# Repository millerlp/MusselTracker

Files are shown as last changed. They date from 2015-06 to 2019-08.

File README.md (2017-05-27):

This repository contains hardware designs and software to create a low-cost datalogger that can be used to track mussel (bivalve molluscs, not muscles) behavior  and temperature over long periods of time. The basic design includes a thermocouple temperature sensor, a hall effect magnetic sensor to sense valve gape, and a 3-D acclerometer/magnetometer to record mussel shell orientation.

Arduino-style code to run the datalogger is available the MusselTracker2 directory. The code requires the use of the MusselTrackerlib library available separately at https://github.com/millerlp/MusselTrackerlib 

Various testing code for individual sensors and the overall circuit board are available in the test_sketches directory. 

Circuit board designs are available in the Eagle_files directory.

Orginally a fork of https://github.com/andrewpetersen/MusselTracker/, now with a wholesale rewrite of the software and hardware. 

******************
    Copyright Luke Miller 2015

    This program is free software: you can redistribute it and/or modify
    it under the terms of the GNU General Public License as published by
    the Free Software Foundation, either version 3 of the License, or
    (at your option) any later version.

    This program is distributed in the hope that it will be useful,
    but WITHOUT ANY WARRANTY; without even the implied warranty of
    MERCHANTABILITY or FITNESS FOR A PARTICULAR PURPOSE.  See the
    GNU General Public License for more details.

    You should have received a copy of the GNU General Public License
    along with this program.  If not, see <http://www.gnu.org/licenses/>.

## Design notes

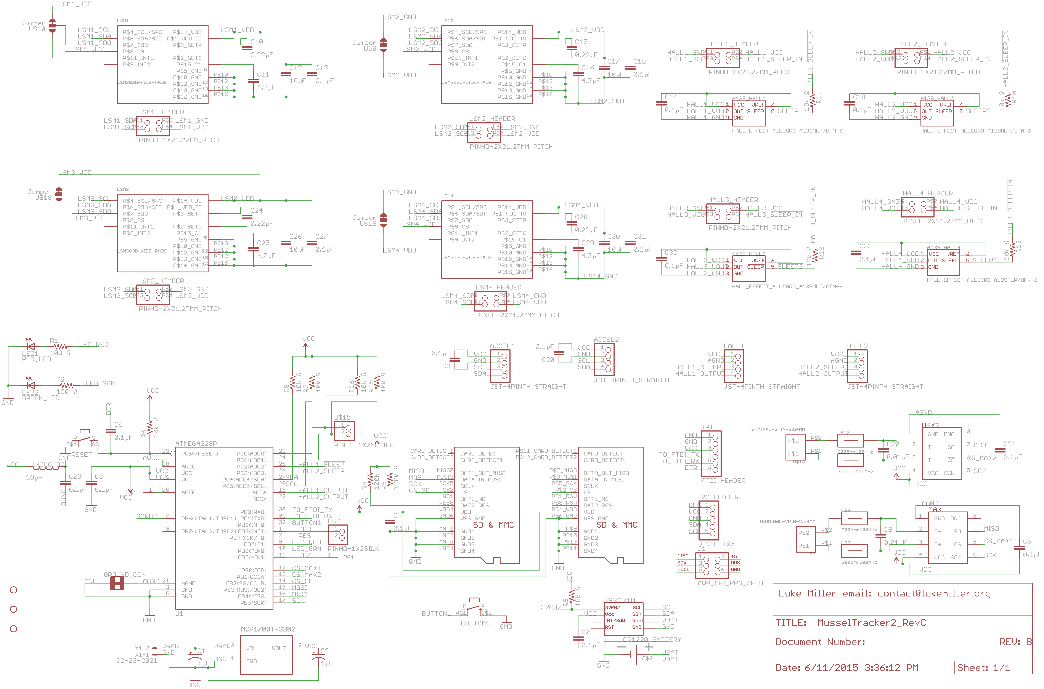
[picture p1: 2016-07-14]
Eagle_files/RevC_schematic.png

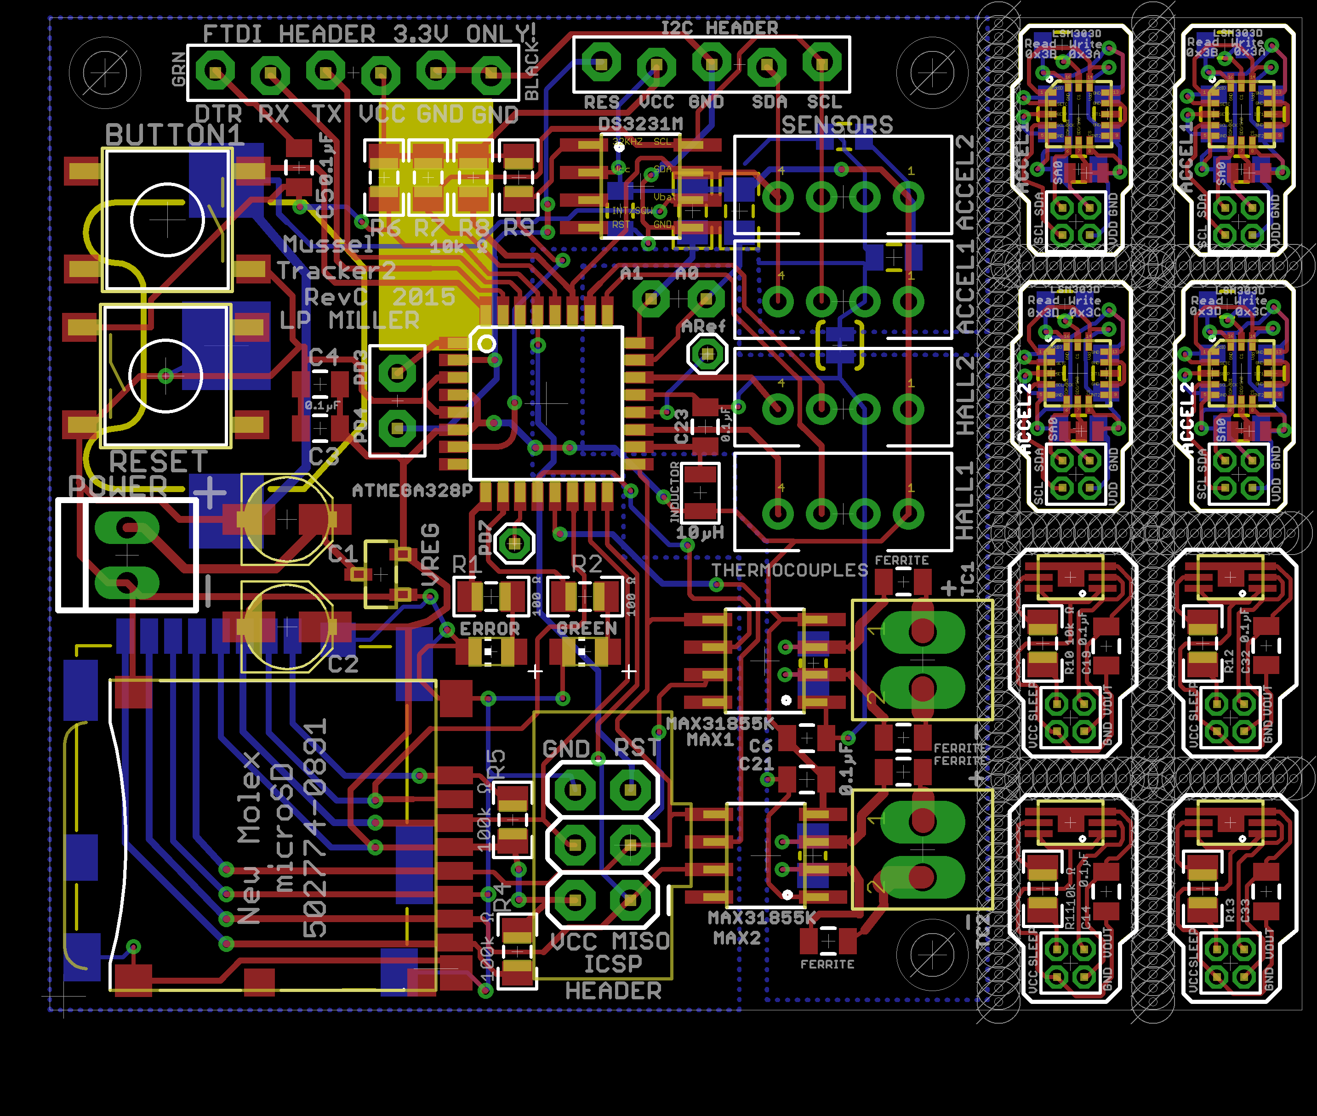
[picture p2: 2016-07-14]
Eagle_files/RevC_top_bottom.png

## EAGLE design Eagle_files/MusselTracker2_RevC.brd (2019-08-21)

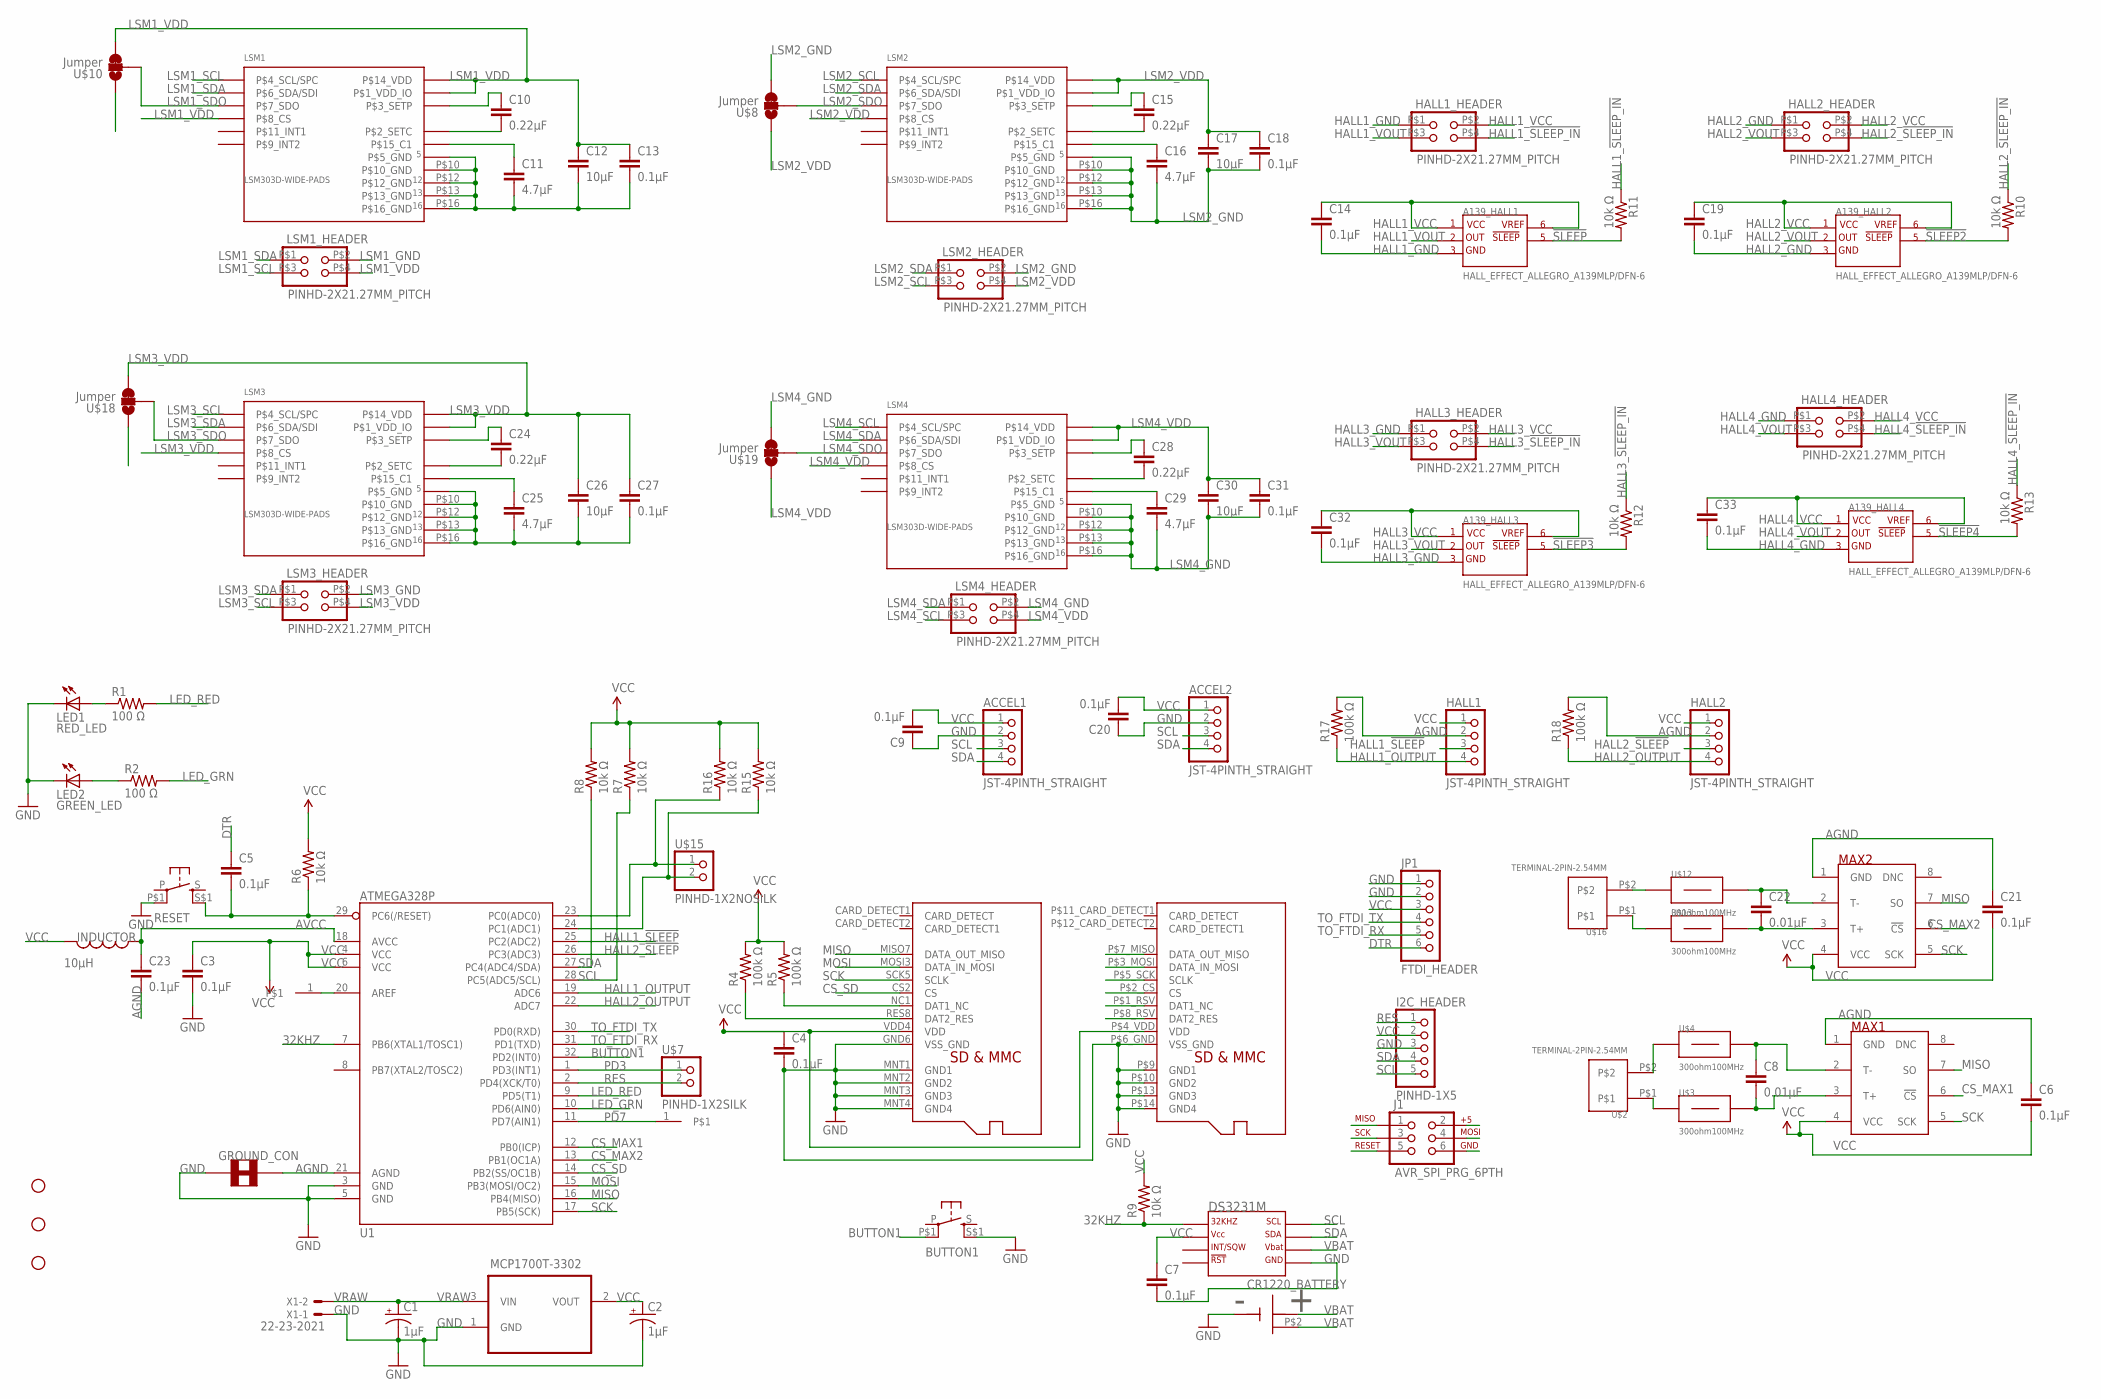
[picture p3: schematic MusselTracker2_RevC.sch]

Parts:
A139_HALL1, A139_HALL2, A139_HALL3, A139_HALL4: HALL_EFFECT_ALLEGRO_A139MLP/DFN-6; A139*_HALL_EFFECT
ACCEL1, ACCEL2: JST-4PINTH_STRAIGHT; JST-PH-4-THM
BUTTON1: PUSHBUTTON_DPST_SMD
C1, C2: 1µF; PANASONIC_B
C3, C4, C5, C6, C7, C9, C13, C14, C18, C19, C20, C21, C23, C27, C31, C32, C33: 0.1µF; 0805
C8, C22: 0.01µF; 0805_CAP_50V_KEMET
C10, C15, C24, C28: 0.22µF; 0805
C11, C16, C25, C29: 4.7µF; 0805
C12, C17, C26, C30: 10µF; 0805
CR1220_BATTERY: CR1220_BATTERY_HOLDERSMD; CR1220_BATTERY_HOLDER_SMD
DS3231M: DS3231MSOIC-8; DS3231M_SOIC8
GROUND_CON: SOLDER_JUMPER_TRACESTANDARD; SJ_2S-TRACE
HALL1, HALL2: JST-4PINTH_STRAIGHT; JST-PH-4-THM
HALL1_HEADER, HALL2_HEADER, HALL3_HEADER, HALL4_HEADER: PINHD-2X21.27MM_PITCH; 2X2_1.27MM
I2C_HEADER: PINHD-1X5; 1X05_BIGLOCK
INDUCTOR: 10µH; I_0805
J1: AVR_SPI_PRG_6PTH; 2X3
JP1: FTDI_HEADER; 1X06-BIGLOCK
LED1: RED_LED; CHIPLED_0805
LED2: GREEN_LED; CHIPLED_0805
LSM1, LSM2, LSM3, LSM4: LSM303D-WIDE-PADS; LSM303D
LSM1_HEADER, LSM2_HEADER, LSM3_HEADER, LSM4_HEADER: PINHD-2X21.27MM_PITCH; 2X2_1.27MM
MAX1, MAX2: MAX31855; SO08
MCP1700T-3302: MCP1700T-3302E/TT; SOT95P237X112-3N
R1, R2: 100 Ω; R0805
R4, R5, R17, R18: 100k Ω; R0805
R6, R7, R8, R9, R10, R11, R12, R13, R15, R16: 10k Ω; R0805
RESET: PUSHBUTTON_DPST_SMD
STANDOFF1, STANDOFF2, STANDOFF3: STAND-OFF
U1: ATMEGA328P; TQFP32-08
U$1: MICROSD_MOLEX_REVERSECURRENT; MICROSD_SOCKET_MOLEX_REVERSEMOUNT
U$2, U$16: TERMINAL-2PIN-2.54MM
U$3, U$4, U$12, U$13: 300ohm100MHz; 0805
U$6, U$17: PINHD-1X1SMALL; 1X01_SMALL
U$7: PINHD-1X2SILK; 1X02
U$8, U$10, U$18, U$19: Jumper; PAD-JUMPER-3-2OF3_NC_BY_TRACE_SMALL
U$14: MICROSD_MOLEX_REVERSEOBSOLETE; MICROSD_SOCKET_MOLEX_REVERSEMOUNT_OBSOLETE
U$15: PINHD-1X2NOSILK; 1X02_NOSILK
X1: 22-23-2021

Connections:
32KHZ: DS3231M.1 (P$1_32KHZ), R9.1, U1.7 (PB6(XTAL1/TOSC1))
!SLEEP: A139_HALL1.P$5, R11.2
!SLEEP2: A139_HALL2.P$5, R10.2
!SLEEP3: A139_HALL3.P$5, R12.2
!SLEEP4: A139_HALL4.P$5, R13.2
AGND: C6.1, C21.1, C23.2, GROUND_CON.2, HALL1.2, HALL2.2, MAX1.1 (GND), MAX2.1 (GND), R17.2, R18.2, U1.21 (AGND)
AVCC: C23.1, INDUCTOR.P$1 (1), U1.18 (AVCC)
BUTTON1: BUTTON1.P$1 (P1), U1.32 (PD2(INT0))
CS_MAX1: MAX1.6 (!CS), U1.12 (PB0(ICP))
CS_MAX2: MAX2.6 (!CS), U1.13 (PB1(OC1A))
CS_SD: U1.14 (PB2(SS/OC1B)), U$1.CS2 (CS), U$14.P$2_CS (CS)
DTR: C5.1, JP1.6
GND: ACCEL1.2, ACCEL2.2, BUTTON1.S$1 (S1), C1.-, C2.-, C3.2, C4.2, C7.2, C9.1, C20.1, CR1220_BATTERY.GND, DS3231M.5 (P$5_GND), GROUND_CON.1, I2C_HEADER.3, J1.6, JP1.1, JP1.2, LED1.C, LED2.C, MCP1700T-3302.1 (GND), RESET.P$1 (P1), U1.3 (GND), U1.5 (GND), U$1.GND6 (VSS_GND), U$1.MNT1 (GND1), U$1.MNT2 (GND2), U$1.MNT3 (GND3), U$1.MNT4 (GND4), U$14.P$6_GND (VSS_GND), U$14.P$9 (GND1), U$14.P$10 (GND2), U$14.P$13 (GND3), U$14.P$14 (GND4), X1.1
HALL1_!SLEEP: HALL1.3, U1.25 (PC2(ADC2))
HALL1_!SLEEP_IN: HALL1_HEADER.P$4 (4), R11.1
HALL1_GND: A139_HALL1.P$3_4, C14.2, HALL1_HEADER.P$1 (1)
HALL1_OUTPUT: HALL1.4, R17.1, U1.19 (ADC6)
HALL1_VCC: A139_HALL1.P$1, A139_HALL1.P$6, C14.1, HALL1_HEADER.P$2 (2)
HALL1_VOUT: A139_HALL1.P$2, HALL1_HEADER.P$3 (3)
HALL2_!SLEEP: HALL2.3, U1.26 (PC3(ADC3))
HALL2_!SLEEP_IN: HALL2_HEADER.P$4 (4), R10.1
HALL2_GND: A139_HALL2.P$3_4, C19.2, HALL2_HEADER.P$1 (1)
HALL2_OUTPUT: HALL2.4, R18.1, U1.22 (ADC7)
HALL2_VCC: A139_HALL2.P$1, A139_HALL2.P$6, C19.1, HALL2_HEADER.P$2 (2)
HALL2_VOUT: A139_HALL2.P$2, HALL2_HEADER.P$3 (3)
HALL3_!SLEEP_IN: HALL3_HEADER.P$4 (4), R12.1
HALL3_GND: A139_HALL3.P$3_4, C32.2, HALL3_HEADER.P$1 (1)
HALL3_VCC: A139_HALL3.P$1, A139_HALL3.P$6, C32.1, HALL3_HEADER.P$2 (2)
HALL3_VOUT: A139_HALL3.P$2, HALL3_HEADER.P$3 (3)
HALL4_!SLEEP_IN: HALL4_HEADER.P$4 (4), R13.1
HALL4_GND: A139_HALL4.P$3_4, C33.2, HALL4_HEADER.P$1 (1)
HALL4_VCC: A139_HALL4.P$1, A139_HALL4.P$6, C33.1, HALL4_HEADER.P$2 (2)
HALL4_VOUT: A139_HALL4.P$2, HALL4_HEADER.P$3 (3)
LED_GRN: R2.2, U1.10 (PD6(AIN0))
LED_RED: R1.2, U1.9 (PD5(T1))
LSM1_GND: C11.2, C12.2, C13.2, LSM1.P$5 (P$5_GND), LSM1.P$10 (P$10_GND), LSM1.P$12 (P$12_GND), LSM1.P$13 (P$13_GND), LSM1.P$16 (P$16_GND), LSM1_HEADER.P$2 (2), U$10.1
LSM1_SCL: LSM1.P$4 (P$4_SCL/SPC), LSM1_HEADER.P$3 (3)
LSM1_SDA: LSM1.P$6 (P$6_SDA/SDI), LSM1_HEADER.P$1 (1)
LSM1_SDO: LSM1.P$7 (P$7_SDO), U$10.2
LSM1_VDD: C12.1, C13.1, LSM1.P$1 (P$1_VDD_IO), LSM1.P$8 (P$8_CS), LSM1.P$14 (P$14_VDD), LSM1_HEADER.P$4 (4), U$10.3
LSM2_GND: C16.2, C17.2, C18.2, LSM2.P$5 (P$5_GND), LSM2.P$10 (P$10_GND), LSM2.P$12 (P$12_GND), LSM2.P$13 (P$13_GND), LSM2.P$16 (P$16_GND), LSM2_HEADER.P$2 (2), U$8.3
LSM2_SCL: LSM2.P$4 (P$4_SCL/SPC), LSM2_HEADER.P$3 (3)
LSM2_SDA: LSM2.P$6 (P$6_SDA/SDI), LSM2_HEADER.P$1 (1)
LSM2_SDO: LSM2.P$7 (P$7_SDO), U$8.2
LSM2_VDD: C17.1, C18.1, LSM2.P$1 (P$1_VDD_IO), LSM2.P$8 (P$8_CS), LSM2.P$14 (P$14_VDD), LSM2_HEADER.P$4 (4), U$8.1
LSM3_GND: C25.2, C26.2, C27.2, LSM3.P$5 (P$5_GND), LSM3.P$10 (P$10_GND), LSM3.P$12 (P$12_GND), LSM3.P$13 (P$13_GND), LSM3.P$16 (P$16_GND), LSM3_HEADER.P$2 (2), U$18.1
LSM3_SCL: LSM3.P$4 (P$4_SCL/SPC), LSM3_HEADER.P$3 (3)
LSM3_SDA: LSM3.P$6 (P$6_SDA/SDI), LSM3_HEADER.P$1 (1)
LSM3_SDO: LSM3.P$7 (P$7_SDO), U$18.2
LSM3_VDD: C26.1, C27.1, LSM3.P$1 (P$1_VDD_IO), LSM3.P$8 (P$8_CS), LSM3.P$14 (P$14_VDD), LSM3_HEADER.P$4 (4), U$18.3
LSM4_GND: C29.2, C30.2, C31.2, LSM4.P$5 (P$5_GND), LSM4.P$10 (P$10_GND), LSM4.P$12 (P$12_GND), LSM4.P$13 (P$13_GND), LSM4.P$16 (P$16_GND), LSM4_HEADER.P$2 (2), U$19.3
LSM4_SCL: LSM4.P$4 (P$4_SCL/SPC), LSM4_HEADER.P$3 (3)
LSM4_SDA: LSM4.P$6 (P$6_SDA/SDI), LSM4_HEADER.P$1 (1)
LSM4_SDO: LSM4.P$7 (P$7_SDO), U$19.2
LSM4_VDD: C30.1, C31.1, LSM4.P$1 (P$1_VDD_IO), LSM4.P$8 (P$8_CS), LSM4.P$14 (P$14_VDD), LSM4_HEADER.P$4 (4), U$19.1
MISO: J1.1, MAX1.7 (SO), MAX2.7 (SO), U1.16 (PB4(MISO)), U$1.MISO7 (DATA_OUT_MISO), U$14.P$7_MISO (DATA_OUT_MISO)
MOSI: J1.4, U1.15 (PB3(MOSI/OC2)), U$1.MOSI3 (DATA_IN_MOSI), U$14.P$3_MOSI (DATA_IN_MOSI)
unnamed: U$2.P$2, U$4.1
unnamed: LED1.A, R1.1
unnamed: U$2.P$1, U$3.1
unnamed: C11.1, LSM1.P$15 (P$15_C1)
unnamed: C10.2, LSM1.P$2 (P$2_SETC)
unnamed: R16.1, U1.23 (PC0(ADC0)), U$15.1
unnamed: U1.20 (AREF), U$17.1
unnamed: R15.1, U1.24 (PC1(ADC1)), U$15.2
unnamed: LED2.A, R2.1
unnamed: U$12.1, U$16.P$2
unnamed: U$13.1, U$16.P$1
unnamed: C24.2, LSM3.P$2 (P$2_SETC)
unnamed: C24.1, LSM3.P$3 (P$3_SETP)
unnamed: C10.1, LSM1.P$3 (P$3_SETP)
unnamed: C15.2, LSM2.P$2 (P$2_SETC)
unnamed: C15.1, LSM2.P$3 (P$3_SETP)
unnamed: C16.1, LSM2.P$15 (P$15_C1)
unnamed: C25.1, LSM3.P$15 (P$15_C1)
unnamed: C28.1, LSM4.P$3 (P$3_SETP)
unnamed: C28.2, LSM4.P$2 (P$2_SETC)
unnamed: C29.1, LSM4.P$15 (P$15_C1)
NC1: R5.1, U$1.NC1 (DAT1_NC), U$14.P$1_RSV (DAT1_NC)
PD3: U1.1 (PD3(INT1)), U$7.1
PD7: U1.11 (PD7(AIN1)), U$6.1
RES: I2C_HEADER.1, U1.2 (PD4(XCK/T0)), U$7.2
RES8: R4.1, U$1.RES8 (DAT2_RES), U$14.P$8_RSV (DAT2_RES)
RESET: C5.2, J1.5, R6.1, RESET.S$1 (S1), U1.29 (PC6(/RESET))
SCK: J1.3, MAX1.5 (SCK), MAX2.5 (SCK), U1.17 (PB5(SCK)), U$1.SCK5 (SCLK), U$14.P$5_SCK (SCLK)
SCL: ACCEL1.3, ACCEL2.3, DS3231M.8 (P$8_SCL), I2C_HEADER.5, R7.1, U1.28 (PC5(ADC5/SCL))
SDA: ACCEL1.4, ACCEL2.4, DS3231M.7 (P$7_SDA), I2C_HEADER.4, R8.1, U1.27 (PC4(ADC4/SDA))
T+_MAX1: C8.2, MAX1.3 (T+), U$3.2
T+_MAX2: C22.2, MAX2.3 (T+), U$13.2
T-_MAX1: C8.1, MAX1.2 (T-), U$4.2
T-_MAX2: C22.1, MAX2.2 (T-), U$12.2
TO_FTDI_RX: JP1.5, U1.31 (PD1(TXD))
TO_FTDI_TX: JP1.4, U1.30 (PD0(RXD))
VBAT: CR1220_BATTERY.P$1 (VBAT), CR1220_BATTERY.P$2, DS3231M.6 (P$6_VBAT)
VCC: ACCEL1.1, ACCEL2.1, C2.+, C3.1, C4.1, C6.2, C7.1, C9.2, C20.2, C21.2, DS3231M.2 (P$2_VCC), HALL1.1, HALL2.1, I2C_HEADER.2, INDUCTOR.P$2 (2), J1.2, JP1.3, MAX1.4 (VCC), MAX2.4 (VCC), MCP1700T-3302.2 (VOUT), R4.2, R5.2, R6.2, R7.2, R8.2, R9.2, R15.2, R16.2, U1.4 (VCC), U1.6 (VCC), U$1.VDD4 (VDD), U$14.P$4_VDD (VDD)
VRAW: C1.+, MCP1700T-3302.3 (VIN), X1.2

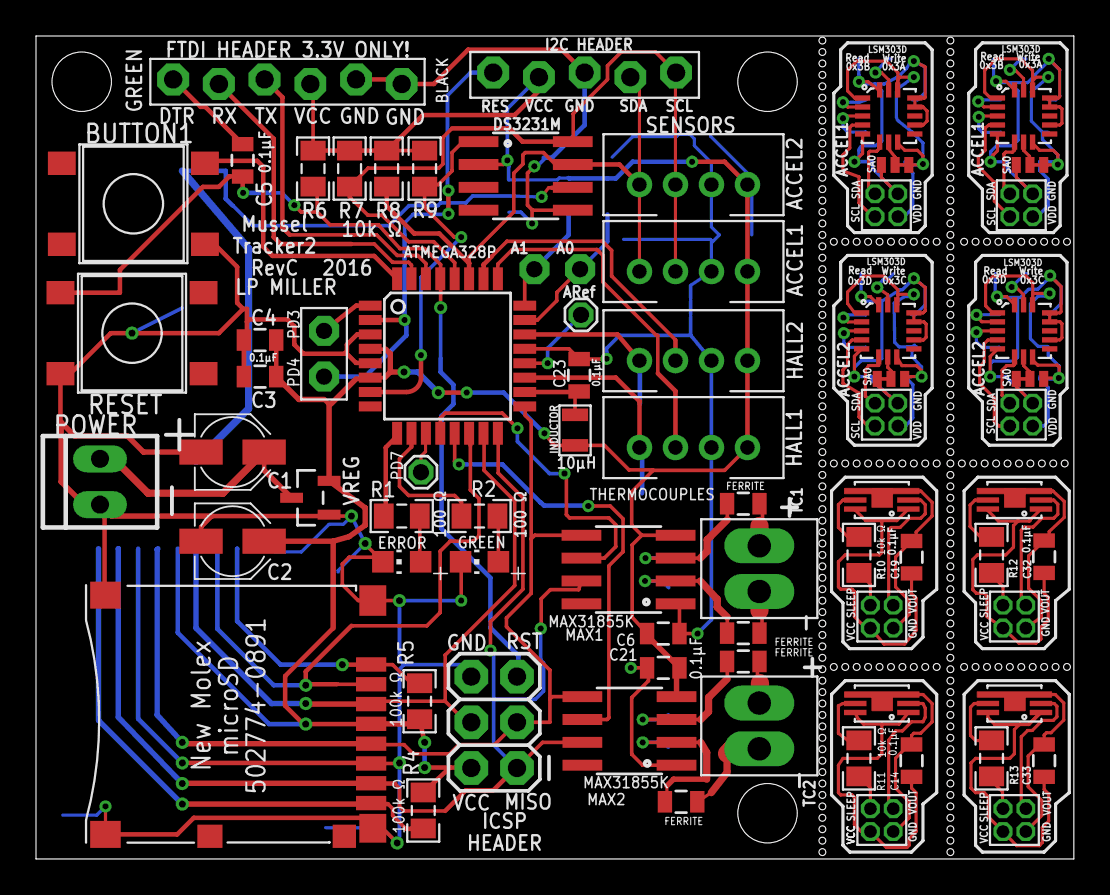
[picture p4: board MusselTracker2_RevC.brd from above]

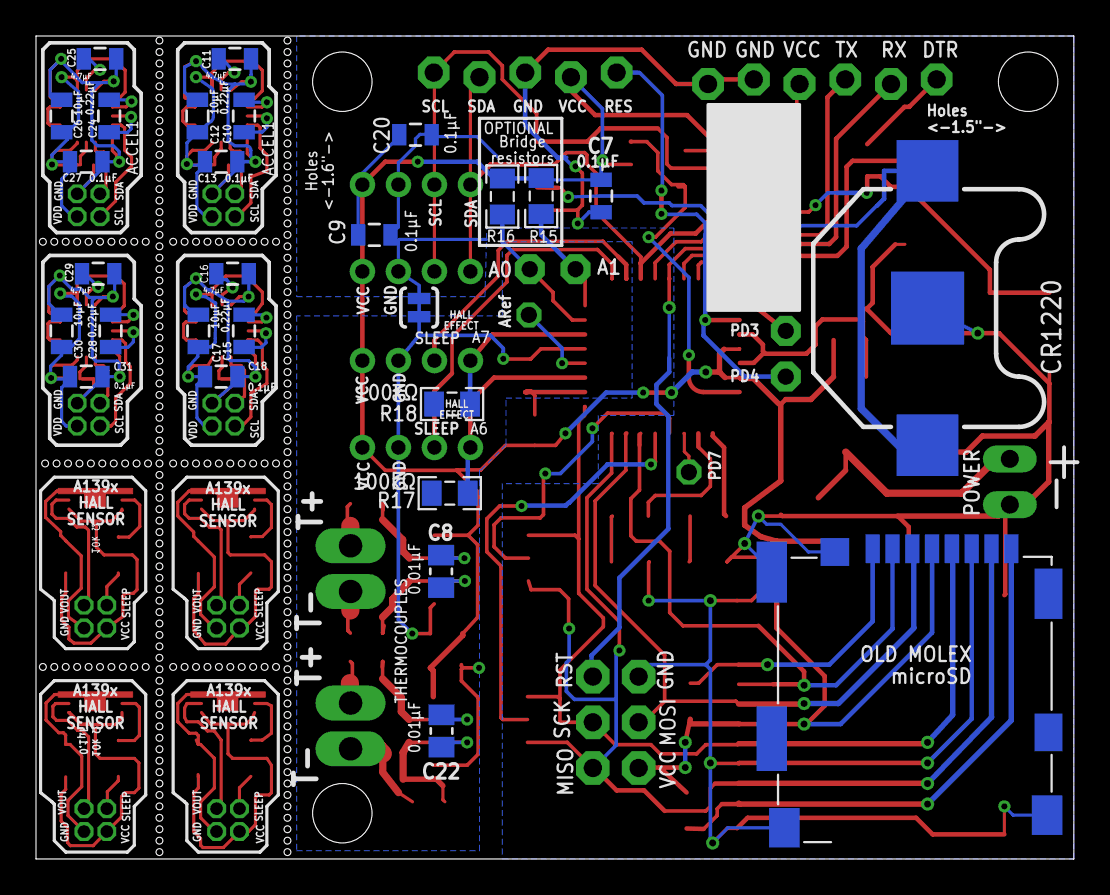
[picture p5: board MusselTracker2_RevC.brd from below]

Board: 2 copper layers, 57.7 x 45.7 mm, 104 parts (28 on the bottom side), 96 nets.

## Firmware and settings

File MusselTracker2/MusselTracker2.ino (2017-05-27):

/* MusselTrackerv2.ino
	Copyright Luke Miller 2015

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
  Code to run a MusselTracker v2 board with attached pairs of
  MAX31855 thermocouple sensors, Allegro A1393 hall effect
  sensors, and LSM303D accelerometer/magnetometers. By default
  this program will start running and saving data to the SD 
  card automatically. 
  
	Entering calibration mode:
		1. Hold button 1 down for at least 3 seconds, but less than 5 seconds
		2. Both red and green leds will flash 5 times when you enable 
			calibration mode. 
		3. You then have ~3 seconds to press button1 again
			to choose whether to calibrate mussel 1 or 2. 
		4. Pressing button1 repeatedly will cycle through 1 flash 
			(mussel 1), 2 flashes (mussel 2) or a red flash (no mussel chosen). 
		5. Once you've chosen the mussel, wait a few seconds for both red and
			green LEDs to flash once. 
		6. The green led will then slowly cycle on and off (1Hz) while it waits 
			for you to get the mussel situated.
		7. With the mussel situated facing north, press button1 briefly to 
			enter the calibration data collection mode. 
		8. When you have finished taking calibration data, press button1 again
			to exit calibration mode and return to normal data collection mode. 
			The red and green LEDs will flash 5 times to denote the end of 
			calibration mode. 
		
	Closing a data file safely:
		1. Hold button 1 down for at least 7 seconds, then release it.
		2. The green LED should flash rapidly 15 times. The previous data
			file will be closed safely, and a new file will be started in
			normal data collection mode. 
  
	Board error codes:
		Red flashes quickly (10Hz): Real Time Clock not set
		Red + Green alternate rapidly: SD card not found
                Red permanently on: SD card not found after data collection started
		Red flash every ~8 seconds: In brownout mode, data collection has stopped

	
	Sensor error codes:
		At the top of every minute, the green LED will flash quickly 5
		times. This lets the user know that error codes will follow 
		during the following 6 seconds, one signal per second. 
		As each second ticks by (1-6), the red error LED will light once 
		if a sensor error code is set for that sensor. The ordering of the 6 potential flashes is:
			1. Accelerometer/magnetometer 1
			2. Accelerometer/magnetometer 2
			3. Thermocouple 1
			4. Thermocouple 2
			5. Hall effect sensor 1
			6. Hall effect sensor 2
		You will need to count off the seconds in your head after you see 
		the 5 quick green flashes to determine which error is being 
		signaled. If there are no errors, the red error LED will not light 
		during this time. 

*/

#include "SdFat.h" // https://github.com/greiman/SdFat
#include <Wire.h>	// built in library, for I2C communications
#include <SPI.h>	// built in library, for SPI communications
#include <EEPROM.h> // built in library, for reading the serial number stored in EEPROM
#include "RTClib.h" // https://github.com/millerlp/RTClib
#include "Adafruit_MAX31855.h" // https://github.com/adafruit/Adafruit-MAX31855-library
#include "LSM303.h" // https://github.com/pololu/lsm303-arduino
#include "MusselTrackerlib.h"	// https://github.com/millerlp/MusselTrackerlib

//******************************
// Data collection rate, enter a value here of 4, 2, or 1 (samples per second)
#define SAMPLES_PER_SECOND 4 // number of samples taken per second (4, 2, or 1)
//******************************

#define ERRLED 5		// Red error LED pin
#define GREENLED 6		// Green LED pin
#define BUTTON1 2 		// BUTTON1 on INT0, pin PD2

// Comment out the following line to remove parts of the
// test code from functioning. 
#define ECHO_TO_SERIAL // For testing serial output over FTDI adapter

// Interval to flash green LED during normal data collection
// For every 10 seconds, enter 10, for every 30 seconds, enter 30
#define PULSE_INTERVAL 10

// ***** TYPE DEFINITIONS *****
typedef enum STATE
{
  STATE_DATA, // collecting data normally
  STATE_ENTER_CALIB, // user wants to calibrate
  STATE_CALIB1, // user chooses to calibrate accel 1
  STATE_CALIB2, // user chooses to calibrate accel 2
  STATE_CALIB_WAIT, // waiting for user to signal mussel is positioned
  STATE_CALIB_ACTIVE, // taking calibration data, button press ends this
  STATE_CLOSE_FILE, // close data file, start new file
} mainState_t;

typedef enum DEBOUNCE_STATE
{
  DEBOUNCE_STATE_IDLE,
  DEBOUNCE_STATE_CHECK,
  DEBOUNCE_STATE_TIME
} debounceState_t;

// main state machine variable, this takes on the various
// values defined for the STATE typedef above. 
mainState_t mainState;

// debounce state machine variable, this takes on the various
// values defined for the DEBOUNCE_STATE typedef above.
volatile debounceState_t debounceState;

//*************
// Create real time clock object
RTC_DS3231 rtc;


//*************
// Create sd card objects
SdFat sd;
SdFile logfile;  // for sd card, this is the file object to be written to
SdFile calibfile; // for sd card, this is the calibration file to write
const byte chipSelect = 10; // define the Chip Select pin for SD card

//************
// Define MAX31855 objects, need 2 of them for the two separate chips
#define CS_MAX1 8 // Chip Select for MAX31855 #1
#define CS_MAX2 9 // Chip Select for MAX31855 #2
Adafruit_MAX31855 thermocouple1(CS_MAX1);
Adafruit_MAX31855 thermocouple2(CS_MAX2);
double temp1 = 0; // hold output from MAX31855 #1
double temp2 = 0; // hold output from MAX31855 #2

//*************
// Define LSM303 accelerometer/magnetometer objects
LSM303 accelcompass1;
LSM303 accelcompass2;

//*************
// Define a HallSensor object (from MusselTrackerlib.h library)
// to access the hall effect sensor functions available in that
// library. 
HallSensor hallsensor;
// Variables to hold hall effect readings
int hallVal1 = 0;
int hallVal2 = 0;
// The HallSensor functions will require an argument to 
// specify which sensor your want, HALL1 or HALL2, so you 
// must always specify that in the hall effect sensor
// function calls. 

// Declare data arrays
uint32_t unixtimeArray[SAMPLES_PER_SECOND]; // store unixtime values temporarily
byte fracSecArray[SAMPLES_PER_SECOND]; // store fracSec values temporarily
int accelcompass1Array[SAMPLES_PER_SECOND][6]; // store accel/compass1 values
int accelcompass2Array[SAMPLES_PER_SECOND][6]; // store accel/compass2 values

int accMagCheck[4]; // store a value from each accel/mag sensor to compare to new values
unsigned int accMagCheckCount[4]; // count up number of matches
unsigned int maxRepeats = 120; // maximum number of accel/mag repeated values allowed before throwing error flag

// Declare initial name for output files written to SD card
char filename[] = "YYYYMMDD_HHMM_00_SN00.csv";
// Define initial name of calibration file for accelerometers
char filenameCalib[] = "CAL0_YYYYMMDD_HHMM_00_SN00.csv";
// Placeholder serialNumber
char serialNumber[] = "SN00";
// Define a flag to show whether the serialNumber value is real or just zeros
bool serialValid = false;
byte mcusr = 0; 	// variable to hold MCU status register codes
byte loopCount = 0; // counter to keep track of data sampling loops
byte fracSec = 0; // counter to keep track of fractional seconds
DateTime newtime; // used to track time in main loop
DateTime oldtime; // used to track time in main loop
byte oldday; 		// used to keep track of midnight transition
DateTime buttonTime; // hold the time since the button was pressed
DateTime chooseTime; // hold the time stamp when a waiting period starts
DateTime calibEnterTime; // hold the time stamp when calibration mode is entered
volatile unsigned long buttonTime1; // hold the initial button press millis() value
byte debounceTime = 20; // milliseconds to wait for debounce
volatile bool buttonFlag = false; // Flag to mark when button was pressed
byte mediumPressTime = 2; // seconds to hold button1 to register a medium press
byte longPressTime = 5; // seconds to hold button1 to register a long press
byte pressCount = 0; // counter for number of button presses
unsigned long prevMillis;	// counter for faster operations
unsigned long newMillis;	// counter for faster operations
// Flags to mark when sensors go bad
bool tc1fail = false;
bool tc2fail = false;
bool hall1fail = false;
bool hall2fail = false;
bool accel1fail = false;
bool accel2fail = false;
// Define two temperature limits for the thermocouples, values outside
// this range will trigger the error notification
float TClowerlimit = 0.0;
float TCupperlimit = 60.0;
int aaFilterBW;		// store accelerometer anti-alias filter bandwidth
byte accFullScale; 	// store accelerometer full scale range +/- g
float accSens; 	// store accelerometer sensitivity (mg/LSB)
int accDataRate;	// store accelerometer sample rate (not the same as datalogger sample rate)
byte magFullScale;	// store magnetometer full scale range (gauss)
float magSens;		// store magnetometer sensitivity (mgauss/LSB)
float magDataRate;	// store magnetometer sample rate (not the same as datalogger sample rate)
//---------------- setup loop ------------------------------------------------
void setup() {
	// Set button1 as an input
	pinMode(BUTTON1, INPUT_PULLUP);
	// Register an interrupt on INT0, attached to button1
	// which will call buttonFunc when the button is pressed.
	attachInterrupt(0, buttonFunc, LOW);
	// Set up the LEDs as output
	pinMode(ERRLED,OUTPUT);
	digitalWrite(ERRLED, LOW);
	pinMode(GREENLED,OUTPUT);
	digitalWrite(GREENLED, LOW);
	// Set the SPI bus chip select pins as outputs
	// for the two MAX31855 thermocouple chips
	pinMode(CS_MAX1, OUTPUT);
	digitalWrite(CS_MAX1, HIGH);
	pinMode(CS_MAX2, OUTPUT);
	digitalWrite(CS_MAX2, HIGH);

	pinMode(4, OUTPUT);
	pinMode(3, OUTPUT);
	
	// Flash green LED to show that we just booted up
	for (byte i = 0; i < 3; i++){
		digitalWrite(GREENLED, HIGH);
		delay(100);
		digitalWrite(GREENLED, LOW);
		delay(100);
	}	
	
	// Brownout detection process.
	mcusr = MCUSR; // Grab the contents of the MCUSR
	MCUSR = 0; // Reset MCUSR to 0 so it is ready for the next go-around.
	// Call the checkMCUSR function to check reason for this restart.
	// If only a brownout is detected, this function will put the board
	// into a permanent sleep that can only be reset with the reset 
	// button or a complete power-down.
	checkMCUSR(mcusr, ERRLED);  // In the MusselTrackerlib library
								
	Serial.begin(57600);
#ifdef ECHO_TO_SERIAL  
	Serial.println(F("Hello"));
	Serial.print(F("MCUSR contents: "));
	printBits(mcusr);
	Serial.println();
	
#endif
	
	// Grab the serial number from the EEPROM memory
	// The character array serialNumber was defined in the preamble
	EEPROM.get(0, serialNumber);
	if (serialNumber[0] == 'S') {
		serialValid = true; // set flag
#ifdef ECHO_TO_SERIAL		
		Serial.print(F("Read serial number: "));
		Serial.println(serialNumber);
#endif		
	} else {
#ifdef ECHO_TO_SERIAL	
		Serial.print(F("No valid serial number: "));
		Serial.println(serialNumber);
		serialValid = false;
#endif		
	}

	// Initialize the Allegro A1393 hall effect sensors
	// There is only one hallsensor object, but you feed it
	// HALL1 or HALL2 as an argument to specify which channel
	// you want to activate and read. 
	hallsensor.begin(HALL1);
	hallsensor.begin(HALL2);

	// Initialize the real time clock DS3231M
	Wire.begin();	// Start the I2C library with default options
	rtc.begin();	// Start the rtc object with default options
	newtime = rtc.now(); // read a time from the real time clock
	printTimeSerial(rtc.now()); // print time to serial monitor
	Serial.println();
	if (newtime.year() < 2015 | newtime.year() > 2035) {
		// There is an error with the clock, halt everything
		while(1){
		// Flash the error led to notify the user
		// This permanently halts execution, no data will be collected
			digitalWrite(ERRLED, !digitalRead(ERRLED));
			delay(100);
		}	
	}

//***************************************
	// Initialize the accelerometer/compass
	// For the LSM303D that has its sa0 pin pulled high (ACCEL1),
	// use the arguments accelcompass1.init(LSM303::device_D, LSM303::sa0_high)
	// to tell the initialization function to look for the correct device
	// When a device type and sa0 pin state are defined, the init() function 
	// will always return true.
	accelcompass1.init(LSM303::device_D, LSM303::sa0_high);
	accelcompass1.enableDefault();
	// Use sa0_low argument for the other accelerometer that has its address 
	// pin set to ground. 
	accelcompass2.init(LSM303::device_D, LSM303::sa0_low);
	accelcompass2.enableDefault();
	// You must set a timeout to handle cases where the sensor dies
	// or otherwise can't be found on the I2C bus, which would hang
	// the whole program without a timeout.
	accelcompass1.setTimeout(20); 
	accelcompass2.setTimeout(20);
	
	// Now set both accelerometers to sample based on the settings
	// in the function accelNormalMode()
	accelNormalMode(accelcompass1);
	accelNormalMode(accelcompass2);
	delay(5);
	// Read back the settings so they can be written to file headers
	getaccelSettings(accelcompass1);
	getaccelSettings(accelcompass2);
//*************************************************************
// SD card setup and read (assumes Serial output is functional already)
	pinMode(chipSelect, OUTPUT);  // set chip select pin for SD card to output
	// Initialize the SD card object
	// Try SPI_FULL_SPEED, or SPI_HALF_SPEED if full speed produces
	// errors on a breadboard setup. 
	if (!sd.begin(chipSelect, SPI_FULL_SPEED)) {
	// If the above statement returns FALSE after trying to 
	// initialize the card, enter into this section and
	// hold in an infinite loop.
		while(1){ // infinite loop due to SD card initialization error
                        digitalWrite(ERRLED, HIGH);
                        delay(100);
                        digitalWrite(ERRLED, LOW);
                        digitalWrite(GREENLED, HIGH);
                        delay(100);
                        digitalWrite(GREENLED, LOW);
		}
	}
	newtime = rtc.now(); // grab the current time
	initFileName(newtime); // generate a file name
	
#ifdef ECHO_TO_SERIAL		
		Serial.print("Writing to ");
		Serial.println(filename);
#endif
	// Start 32.768kHz clock signal on TIMER2. 
	// Supply the current time value as the argument, returns 
	// an updated time
	newtime = startTIMER2(rtc.now());
	
	oldtime = newtime; // store the current time value
	oldday = oldtime.day(); // store the current day value
	
	mainState = STATE_DATA; // Start the main loop in data-taking state
}

void loop() {
	delay(2); // trying this to quell bogus sd writes
	// Always start the loop by checking the time
	newtime = rtc.now(); // Grab the current time
	
	
	//-------------------------------------------------------------
	// Begin loop by checking the debounceState to 
	// handle any button presses
 	switch (debounceState) {
		// debounceState should normally start off as 
		// DEBOUNCE_STATE_IDLE until button1 is pressed,
		// which causes the state to be set to 
		// DEBOUNCE_STATE_CHECK
		//************************************
		case DEBOUNCE_STATE_IDLE:
			// Do nothing in this case
		break;
		//************************************
		case DEBOUNCE_STATE_CHECK:
			// If the debounce state has been set to 
			// DEBOUNCE_STATE_CHECK by the buttonFunc interrupt,
			// check if the button is still pressed
			if (digitalRead(BUTTON1) == LOW) {
				if (millis() > buttonTime1 + debounceTime) {
					// If the button has been held long enough to 
					// be a legit button press, switch to 
					// DEBOUNCE_STATE_TIME to keep track of how long 
					// the button is held
					debounceState = DEBOUNCE_STATE_TIME;
					buttonTime = rtc.now();
				} else {
					// If button is still pressed, but the debounce 
					// time hasn't elapsed, remain in this state
					debounceState = DEBOUNCE_STATE_CHECK;
				}
			} else {
				// If button1 is high again when we hit this
				// case in DEBOUNCE_STATE_CHECK, it was a false trigger
				// Reset the debounceState
				debounceState = DEBOUNCE_STATE_IDLE;
				buttonFlag = false;
				// Restart the button1 interrupt
				attachInterrupt(0, buttonFunc, LOW);
			}
		break; // end of case DEBOUNCE_STATE_CHECK
		//*************************************
		case DEBOUNCE_STATE_TIME:
			if (digitalRead(BUTTON1) == HIGH) {
				// If the user released the button, now check how
				// long the button was depressed. This will determine
				// which state the user wants to enter.
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

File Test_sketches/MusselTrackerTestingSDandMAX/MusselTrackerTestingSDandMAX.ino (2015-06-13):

/* MusselTrackerTesting
  Code to test what portions of a newly assembled 
  Mussel Tracker v2 board are functional
  
  **Tested as working on 2015-06-11 on a 
  Mussel Tracker v2 RevB circuit board with the
  fix applied to supply VCC power to MAX31855 chip 2

*/

#include "SdFat.h" // https://github.com/greiman/SdFat
#include <Wire.h>
#include <SPI.h>
#include "RTClib.h" // https://github.com/millerlp/RTClib
#include <Adafruit_MAX31855.h> // https://github.com/adafruit/Adafruit-MAX31855-library


#define ERRLED 5
#define GREENLED 6

// Comment out any of the following 4 lines to remove parts of the
// test code from functioning. 
#define Serialtest // For testing serial output over FTDI adapter
#define RTCtest // For testing DS3231 function (requires Serial to be working)
#define SDtest	// For testing SD card slot function, requires Serial to be working
#define MAXtest // For testing MAX31855 thermocouple 

// Create real time clock object
RTC_DS3231 RTC;

// Create sd objects
SdFat sd;
SdFile logfile;  // for sd card, this is the file object to be written to
SdFile setfile; // for sd card, this is the settings file to read from
const byte chipSelect = 10; // define the Chip Select pin for SD card
// Serial streams
ArduinoOutStream cout(Serial);


#define CS_MAX1 8 // Chip Select for MAX31855 #1
#define CS_MAX2 9 // Chip Select for MAX31855 #2
// Define MAX31855 objects, need 2 of them for the two separate chips
Adafruit_MAX31855 thermocouple1(CS_MAX1);
Adafruit_MAX31855 thermocouple2(CS_MAX2);
double temp1 = 0; // hold output from MAX31855 #1
double temp2 = 0; // hold output from MAX31855 #2

void setup() {


  // put your setup code here, to run once:
#ifdef Serialtest  
  Serial.begin(57600);
  Serial.println("Hello");
#endif
  
  pinMode(ERRLED,OUTPUT);
  digitalWrite(ERRLED, LOW);
  pinMode(GREENLED,OUTPUT);
  digitalWrite(GREENLED, LOW);
  
	// Set the chip select pins as outputs
	pinMode(CS_MAX1, OUTPUT);
	digitalWrite(CS_MAX1, HIGH);
	pinMode(CS_MAX2, OUTPUT);
	digitalWrite(CS_MAX2, HIGH);

#ifdef RTCtest 
  Wire.begin();
  RTC.begin();
  RTC.adjust(DateTime(__DATE__, __TIME__));
#endif



//*************************************************************
// SD card setup and read (assumes Serial output is functional already)
#ifdef SDtest
	pinMode(chipSelect, OUTPUT);  // set chip select pin for SD card to output
	// Initialize the SD card object
	// Try SPI_FULL_SPEED, or SPI_HALF_SPEED if full speed produces
	// errors on a breadboard setup. 
	if (!sd.begin(chipSelect, SPI_FULL_SPEED)) {
    if (sd.card()->errorCode()) {
      cout << F(
             "\nSD initialization failed.\n"
             "Do not reformat the card!\n"
             "Is the card correctly inserted?\n"
             "Is chipSelect set to the correct value?\n"
             "Does another SPI device need to be disabled?\n"
             "Is there a wiring/soldering problem?\n");
      cout << F("\nerrorCode: ") << hex << showbase;
      cout << int(sd.card()->errorCode());
      cout << F(", errorData: ") << int(sd.card()->errorData());
      cout << dec << noshowbase << endl;
      return;
    }
    cout << F("\nCard successfully initialized.\n");
    if (sd.vol()->fatType() == 0) {
      cout << F("Can't find a valid FAT16/FAT32 partition.\n");
      reformatMsg();
      return;
    }
    if (!sd.vwd()->isOpen()) {
      cout << F("Can't open root directory.\n");
      return;
    }
    cout << F("Can't determine error type\n");
    return;
  }
  cout << F("\nCard successfully initialized.\n");
  cout << endl;

  uint32_t size = sd.card()->cardSize();
  if (size == 0) {
    cout << F("Can't determine the card size.\n");
    cardOrSpeed();
    return;
  }
  uint32_t sizeMB = 0.000512 * size + 0.5;
  cout << F("Card size: ") << sizeMB;
  cout << F(" MB (MB = 1,000,000 bytes)\n");
  cout << endl;
  cout << F("Volume is FAT") << int(sd.vol()->fatType());
  cout << F(", Cluster size (bytes): ") << 512L * sd.vol()->blocksPerCluster();
  cout << endl << endl;

  cout << F("Files found (date time size name):\n");
  sd.ls(LS_R | LS_DATE | LS_SIZE);

  if ((sizeMB > 1100 && sd.vol()->blocksPerCluster() < 64)
      || (sizeMB < 2200 && sd.vol()->fatType() == 32)) {
    cout << F("\nThis card should be reformatted for best performance.\n");
    cout << F("Use a cluster size of 32 KB for cards larger than 1 GB.\n");
    cout << F("Only cards larger than 2 GB should be formatted FAT32.\n");
    reformatMsg();
    return;
  }
#endif 



}

void loop() {
  // put your main code here, to run repeatedly:
  digitalWrite(ERRLED,HIGH);
  delay(500);
  digitalWrite(GREENLED,HIGH);
  delay(250);
  digitalWrite(ERRLED, LOW);
  digitalWrite(GREENLED,LOW);
  delay(250);

#ifdef Serialtest
  Serial.println(millis());
#endif

#ifdef RTCtest  
  printTime(RTC.now());
  Serial.println();
#endif

#ifdef MAXtest
	temp1 = thermocouple1.readInternal();
	temp2 = thermocouple2.readInternal();
	Serial.print("Internal temp1: ");
	Serial.print(temp1);
	Serial.print("C, temp2: ");
	Serial.println(temp2);
#endif

} // end of main loop




//------------------------------------------------
//------------------------------------------------
// printTime function takes a DateTime object from
// the real time clock and prints the date and time 
// to the serial monitor. 
void printTime(DateTime now){
	Serial.print(now.year(), DEC);
    Serial.print('-');
    Serial.print(now.month(), DEC);
    Serial.print('-');
    Serial.print(now.day(), DEC);
    Serial.print(' ');
    Serial.print(now.hour(), DEC);
    Serial.print(':');
	if (now.minute() < 10) {
		Serial.print("0");
	}
    Serial.print(now.minute(), DEC);
    Serial.print(':');
	if (now.second() < 10) {
		Serial.print("0");
	}
    Serial.print(now.second(), DEC);
	// You may want to print a newline character
	// after calling this function i.e. Serial.println();
}

void cardOrSpeed() {
  cout << F("Try another SD card or reduce the SPI bus speed.\n");
  cout << F("Edit spiSpeed in this program to change it.\n");
}

void reformatMsg() {
  cout << F("Try reformatting the card.  For best results use\n");
  cout << F("the SdFormatter program in SdFat/examples or download\n");
  cout << F("and use SDFormatter from www.sdcard.org/downloads.\n");
}

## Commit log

2015-05-06 Entry for a boards.txt file so that Arduino IDE knows how to handle the MusselTracker v1 boards.
2015-05-06 Nothing new here currently, just making a copy of the original sketch from version 1.
2015-06-11 Trying to test out assembled boards with these sketches
2015-06-13 This probably doesn't work with the newest version of the mussel tracker library, but it did work at one point
    [MT_library_test.ino]
2015-06-13 Just a quick test of a prototype library for the
    Allegro hall effect sensors. It worked originally, but I think the library
    has changed enough that it won't work in the future.
    [Hall_interface.ino]
2015-06-13 Tested as working with MusselTracker v2 RevB breakout board
2015-06-29 Updated to burn the last of the boards. This shouldn't be needed any further.
    [serial_number_generator.ino]
2015-06-29 Minimal functional version, with file naming, serial number extraction, temperature recording to SD at 1 second intervals.
2015-06-30 Dealing with serial number output, added error code explanations.
    [TC_calibrate.ino]
2015-06-30 Had to re-burn some serial numbers for some reason
    [serial_number_generator.ino]
2015-07-02 Beginning the actual data collection program in earnest. Need to add calibration routine and handling button presses.
2015-07-02 Added the basic bones of a button interrupt and enter calibration mode section of code.
2015-07-02 Fixed bug trying to send DateTime object directly to Serial.print() that was causing a compile hang with no errors.
    [MusselTracker2.ino]
2015-07-06 Make the flag voltatile
2015-07-06 Fleshed out the remainder of the calibration states. Need to check into changing accel sample rate during calibration mode.
2015-07-06 Added code to switch accel into high-frequency sampling mode during calibration. Finished up the calibration routine, including adding directions at the top of the program. Added some pin toggles to 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
2015-07-07 Needed to put the serial print delay back to 10ms so it would read out properly.
2015-07-07 Added flags for various failures of sensors, but need to come up with a time-efficient way to signal failures via the LEDs.
    [MusselTracker2.ino]
2015-07-07 Added flashing for error codes when sensors fail, added comments for preamble to make sense of the error flashes.
    [MusselTracker2.ino]
2015-07-07 Updated to current working version
2015-07-07 Added code to make use of MCU status register to look for brownout events and force the avr into a low-power sleep mode if a brownout occurs. Also modified the output file header to include the MCUSR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
    [MusselTracker2.ino]
2015-07-07 Adding error code for brownout situation, set green led pulse interval to 10. Loaded this version up to all 15 boards on 2015-07-07 16:00
    [MusselTracker2.ino]
2015-07-08 Reverted to accel defaults for normal data taking mode. The anti-aliasing filter was probably not enabled correctly by me.
    [MusselTracker2.ino]
2015-07-08 Fleshed out the various filter settings for the accelerometer, settled on settings for calibration and normal data modes. We don't want the high-pass filter enabled on the accel channel since that el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
2015-07-08 Swapped out time-reset utility program for an easier version that works from the serial monitor.
    [settime_Serial.ino]
2015-07-10 Added function getaccelSettings to read accelerometer/magnetometer settings and then write them to the headers of the output files.
2015-07-11 Adding code to overwrite bad hall readings with -9999
2015-07-12 Changing the magnetometer range to +/- 8 gauss to minimize the chances of neighboring magnets possibly railing the sensor. Altered the calibration anti-alias filter to 50Hz for the accelerometer sinc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
2015-07-13 Added green LED blink every 10 seconds to help see how well adjacent MusselTracker boards are synchronized.
2016-06-28 Added code to check if accel or magnetometer values are repeating constantly, which signals a non-functional sensor and should light the red error LED.
    [MusselTracker2.ino]
2016-06-29 Simple program to output accel/mag raw data to Serial
    Run this with the Serial Monitor open to see a live stream of
    accelerometer and magnetometer. This will only work with a single
    LSM303D chip attached, and it must be the version with the sa0 pin
    pulled high.
2016-06-30 Adding comment for red light error code
    [MusselTracker2.ino]
2016-07-14 Adding board schematics
2016-07-19 Updating for board builds
2016-07-19 Updating for new board builds
2018-01-03 Demo sketch for OLED screen
    This version hooks to a I2C OLED 128x64 display screen to show updates of the two temperature channels and one Hall effect channel for classroom demonstration.
2019-08-21 Eagle design files
    [MusselTracker2_RevC.brd, MusselTracker2_RevC.sch]
